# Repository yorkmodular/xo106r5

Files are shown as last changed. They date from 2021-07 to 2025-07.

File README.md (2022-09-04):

The XO106r5 is a logical progression from its predecessors - although it no longer contains any 40106 ICs, it's still a good source of square-wave glitchiness along with a filter should you want to round off some of the rough edges.

It's also a lot bigger - 22HP.

The salient features are:

*    4 AVR-based square-wave oscillators with V/oct response good for around 5 octaves. There are fine-tune pots on the back side of the PCB.
*    Voltage-controlled pulse width for each oscillator
*    Oscillator firmware is available under a permissive license.
*    Patchable Sallen-Key low-pass filter - use it, or don't; it's something of a nod to the previous incarnations of the module.
*   Patchable logic matrix - this is the big step from the previous versions. 

The oscillators are no longer hardwired to the logic IC; you can patch things together how you want, or not at all - you can also patch in external sources as you see fit. The logic IC itself is socketed so you can replace it with a different, pin-compatible, IC should you wish to change the voicing of the module. The 'default' option is a CD4070 (quad XOR) but alternatives include the 4001, 4011 and 4093.

THE DEFAULT CONFIGURATION FOR THIS WILL BE A PCB/PANEL/FIRMWARE SET - I don't recommend this is as a beginners project.

* The firmware for this module is the same as that for the Squascillator VCO - you will need to burn four firmware ICs.
* The two jumpers (JP1 and JP2) control the response of the filter pots - use a blob of solder to bridge the centre pad with one of the outer pads

The terminally curious can view [Johnny Beaver's demo of a prototype unit in action on YouTube ...](https://youtu.be/iXnucviOB_w)

### Panel files

If want to roll your own panel, there are two panel files in the repo - the KiCAD board file is the same one that I use for the panels of 'retail' units. If 
you have some KiCAD-fu then you can customise it to your heart's content and then send the resulting file off to you friendly local fab for production. The DXF
file consists of the Edge-Cuts PCB layer and can be consumed by most laser cutters - this panel is unadorned.

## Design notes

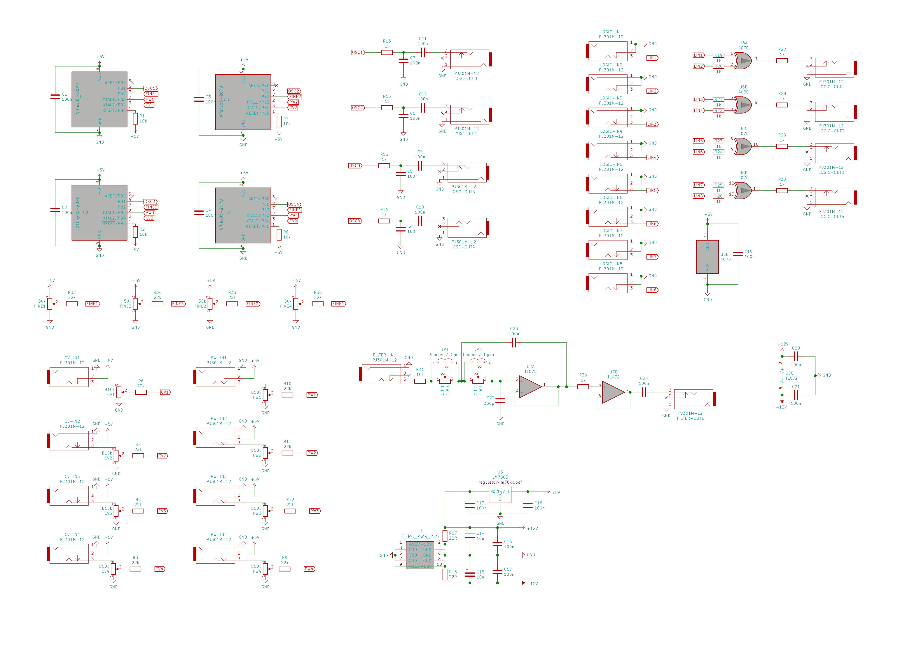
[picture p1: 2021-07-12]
xo106r5-schematic.png

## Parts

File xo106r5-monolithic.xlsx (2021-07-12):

Reference | Quantity | Value
C14 C15 | 2 | 10u
C1 C2 C3 C4 C13 C16 C17 C18 C19 C20 C21 | 11 | 100n
C22 | 1 | 330p
C5 C6 C7 C8 C9 C10 C11 C12 C23 C24 | 10 | 100n
CUT1 CUT2 | 2 | 100k
CV1 PW1 CV2 PW2 CV3 PW3 PW4 CV4 | 8 | B10k
FINE1 FINE2 FINE3 FINE4 | 4 | 50k
J1 | 1 | EURO_PWR_2x5
JP1 JP2 | 2 | Jumper_3_Open
LOGIC-IN1 LOGIC-OUT1 FILTER-IN1 FILTER-OUT1 OSC-OUT1 CV-IN1 PW-IN1 LOGIC-IN2 LOGIC-OUT2 OSC-OUT2 CV-IN2 PW-IN2 LOGIC-IN3 LOGIC-OUT3 OSC-OUT3 CV-IN3 PW-IN3 LOGIC-IN4 LOGIC-OUT4 OSC-OUT4 CV-IN4 PW-IN4 LOGIC-IN5 LOGIC-IN6 LOGIC-IN7 LOGIC-IN8 | 26 | PJ301M-12
R1 R2 R7 R8 R31 | 5 | 10k
R17 R18 | 2 | 22R
R13 R14 R15 R16 R19 R20 R21 R22 R23 R24 R25 R26 R27 R28 R29 R30 R36 | 17 | 1k
R3 R4 R5 R6 R9 R10 R11 R12 R32 R33 R34 R35 | 12 | 22k
U1 U2 U3 U4 | 4 | ATtiny85-20PU
U5 | 1 | LM7805
U6 | 1 | CD4070
U7 | 1 | TL072

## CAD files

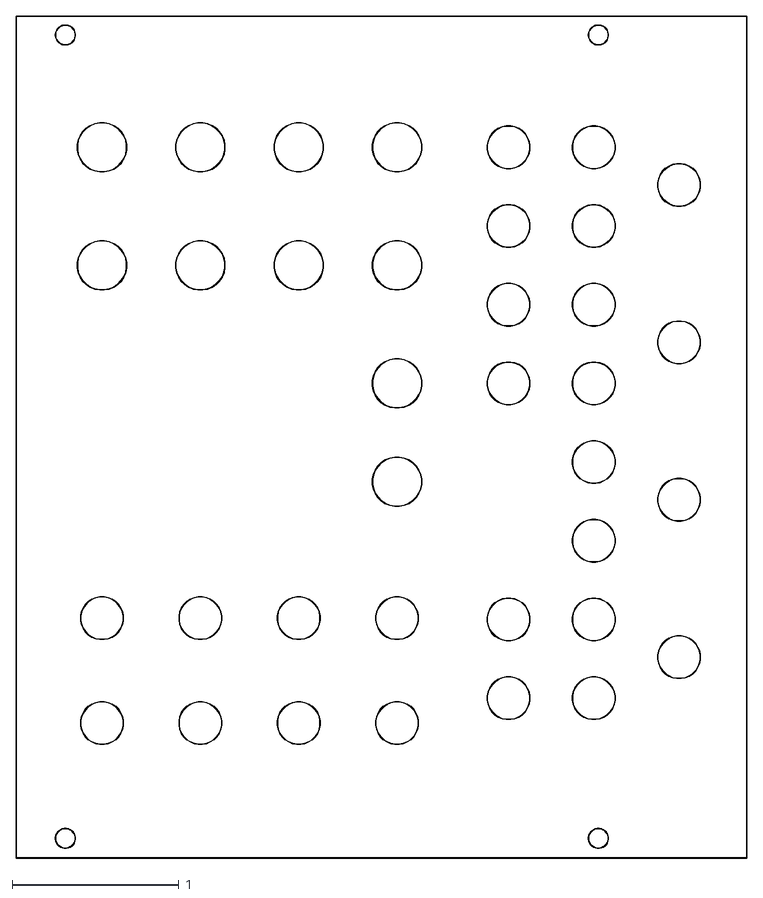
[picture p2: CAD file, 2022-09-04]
xo106r5-22hp-Edge_Cuts.dxf
4.39 x 5.06

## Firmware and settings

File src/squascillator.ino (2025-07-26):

#include <avr/io.h>
#include <avr/interrupt.h>
#include <avr/pgmspace.h>
#define CV_INPUT A2
#define TUNE_INPUT A1
#define DUTY_INPUT A3

#define WAVETABLE_LENGTH 256
#define MAPTABLE_LENGTH 1024

// 1V/octave lookup table - the values are phase increments. Base frequency is
// approximately 30Hz.
const uint16_t freqTable[MAPTABLE_LENGTH] PROGMEM = {
  69, 69, 69, 69, 70, 70, 70, 70, 70, 71, 71, 71, 71, 72, 72, 72, 72, 73, 73, 73, 73, 74, 74, 74,
  74, 75, 75, 75, 75, 76, 76, 76, 76, 77, 77, 77, 77, 78, 78, 78, 79, 79, 79, 79, 80, 80, 80, 80,
  81, 81, 81, 81, 82, 82, 82, 83, 83, 83, 83, 84, 84, 84, 85, 85, 85, 85, 86, 86, 86, 87, 87, 87,
  88, 88, 88, 88, 89, 89, 89, 90, 90, 90, 91, 91, 91, 91, 92, 92, 92, 93, 93, 93, 94, 94, 94, 95,
  95, 95, 96, 96, 96, 97, 97, 97, 98, 98, 98, 99, 99, 99, 100, 100, 100, 101, 101, 101, 102, 102,
  102, 103, 103, 103, 104, 104, 104, 105, 105, 105, 106, 106, 106, 107, 107, 108, 108, 108,
  109, 109, 109, 110, 110, 111, 111, 111, 112, 112, 112, 113, 113, 114, 114, 114, 115, 115,
  115, 116, 116, 117, 117, 117, 118, 118, 119, 119, 119, 120, 120, 121, 121, 122, 122, 122,
  123, 123, 124, 124, 124, 125, 125, 126, 126, 127, 127, 127, 128, 128, 129, 129, 130, 130,
  130, 131, 131, 132, 132, 133, 133, 134, 134, 134, 135, 135, 136, 136, 137, 137, 138, 138,
  139, 139, 140, 140, 141, 141, 141, 142, 142, 143, 143, 144, 144, 145, 145, 146, 146, 147,
  147, 148, 148, 149, 149, 150, 150, 151, 151, 152, 152, 153, 153, 154, 155, 155, 156, 156,
  157, 157, 158, 158, 159, 159, 160, 160, 161, 161, 162, 163, 163, 164, 164, 165, 165, 166,
  166, 167, 168, 168, 169, 169, 170, 170, 171, 172, 172, 173, 173, 174, 175, 175, 176, 176,
  177, 178, 178, 179, 179, 180, 181, 181, 182, 182, 183, 184, 184, 185, 185, 186, 187, 187,
  188, 189, 189, 190, 191, 191, 192, 193, 193, 194, 194, 195, 196, 196, 197, 198, 198, 199,
  200, 201, 201, 202, 203, 203, 204, 205, 205, 206, 207, 207, 208, 209, 210, 210, 211, 212,
  212, 213, 214, 215, 215, 216, 217, 217, 218, 219, 220, 220, 221, 222, 223, 223, 224, 225,
  226, 226, 227, 228, 229, 230, 230, 231, 232, 233, 233, 234, 235, 236, 237, 237, 238, 239,
  240, 241, 242, 242, 243, 244, 245, 246, 246, 247, 248, 249, 250, 251, 252, 252, 253, 254,
  255, 256, 257, 258, 258, 259, 260, 261, 262, 263, 264, 265, 266, 266, 267, 268, 269, 270,
  271, 272, 273, 274, 275, 276, 277, 277, 278, 279, 280, 281, 282, 283, 284, 285, 286, 287,
  288, 289, 290, 291, 292, 293, 294, 295, 296, 297, 298, 299, 300, 301, 302, 303, 304, 305,
  306, 307, 308, 309, 310, 311, 312, 313, 314, 316, 317, 318, 319, 320, 321, 322, 323, 324,
  325, 326, 328, 329, 330, 331, 332, 333, 334, 335, 337, 338, 339, 340, 341, 342, 343, 345,
  346, 347, 348, 349, 350, 352, 353, 354, 355, 356, 358, 359, 360, 361, 363, 364, 365, 366,
  367, 369, 370, 371, 372, 374, 375, 376, 378, 379, 380, 381, 383, 384, 385, 387, 388, 389,
  391, 392, 393, 395, 396, 397, 399, 400, 401, 403, 404, 405, 407, 408, 410, 411, 412, 414,
  415, 417, 418, 419, 421, 422, 424, 425, 426, 428, 429, 431, 432, 434, 435, 437, 438, 440,
  441, 443, 444, 446, 447, 449, 450, 452, 453, 455, 456, 458, 459, 461, 463, 464, 466, 467,
  469, 470, 472, 474, 475, 477, 479, 480, 482, 483, 485, 487, 488, 490, 492, 493, 495, 497,
  498, 500, 502, 503, 505, 507, 509, 510, 512, 514, 515, 517, 519, 521, 523, 524, 526, 528,
  530, 531, 533, 535, 537, 539, 541, 542, 544, 546, 548, 550, 552, 553, 555, 557, 559, 561,
  563, 565, 567, 569, 571, 573, 574, 576, 578, 580, 582, 584, 586, 588, 590, 592, 594, 596,
  598, 600, 602, 604, 606, 608, 611, 613, 615, 617, 619, 621, 623, 625, 627, 629, 632, 634,
  636, 638, 640, 642, 645, 647, 649, 651, 653, 656, 658, 660, 662, 664, 667, 669, 671, 674,
  676, 678, 680, 683, 685, 687, 690, 692, 694, 697, 699, 701, 704, 706, 709, 711, 713, 716,
  718, 721, 723, 726, 728, 730, 733, 735, 738, 740, 743, 745, 748, 751, 753, 756, 758, 761,
  763, 766, 769, 771, 774, 776, 779, 782, 784, 787, 790, 792, 795, 798, 800, 803, 806, 809,
  811, 814, 817, 820, 822, 825, 828, 831, 834, 836, 839, 842, 845, 848, 851, 854, 856, 859,
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
};

volatile uint16_t syncPhaseAcc, syncPhaseInc, baseFreq, syncOffset, finetune, duty;
volatile uint8_t current_wavetable = 0;

uint16_t mapFreq(uint16_t input) {
  return pgm_read_word_near(freqTable + input);
}
uint16_t acc, a1_level, buff_step;

void audioOn() {
  PLLCSR = 1 << PCKE | 1 << PLLE;
  TIMSK = 0;

  // Timer/counter1 control register
  // PWM1A - Enable pulsewidth modulator A
  // COM1A0 - Togle OC1A output line on match
  // CS11 - /2 clock prescaler
  TCCR1 = 1 << PWM1A | 2 << COM1A0 | 1 << CS11;
  OCR1A = 128;
  pinMode(1, OUTPUT);
  pinMode(CV_INPUT, INPUT);
  pinMode(TUNE_INPUT, INPUT);
  pinMode(DUTY_INPUT, INPUT);
  pinMode(0, OUTPUT);
  TCCR0A = (1 << WGM00) | (1 << WGM01);
  TCCR0B = 1 << WGM02 | 2 << CS00;
  TIMSK = 1 << OCIE0A;  // Compare match A
  OCR0A = 29;
  syncPhaseAcc = 0;
}

void setup() {
  audioOn();
}

void loop() {
  // Desired frequency - resolution is 5V / 1024 steps = 4.8mV
  // The lookup table for mapFreq yields a response pretty close to 1V/oct
  baseFreq = mapFreq(analogRead(CV_INPUT));
  finetune = -128 + (analogRead(TUNE_INPUT) >> 2);
  duty = map(analogRead(DUTY_INPUT), 0, 1023, 16, 240);
  syncPhaseInc = baseFreq + finetune;
}

// The interrupt service routine - this is where it all happens.
//
// On the ATTiny85, there's a conflict relating to TIMER0_OVF_vect in
// some cores so we use the comparator instead. The net result is the
// same.
//
// - Increment the phase accumulator
// - Convert the accumulator value to an 8-bit number corresponding to
//   the step in the wavetable
// - Read the appropriate wavetable value
// - Write it to the PWM pinf

ISR(TIMER0_COMPA_vect) {
  uint8_t val, step;

  syncPhaseAcc += (syncPhaseInc >> 1);

  step = syncPhaseAcc >> 8;

  val = (step <= duty) ? 0xff : 0x00;

  OCR1A = val;
}
